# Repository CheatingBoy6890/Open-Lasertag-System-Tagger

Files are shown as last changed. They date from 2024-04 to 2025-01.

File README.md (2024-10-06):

<div align="center">
  
PCBWay
###### Partnering with PCBway.
</div>
<br/>

# Open-Lasertag-System

_DSC8902

---


https://commons.wikimedia.org/w/index.php?curid=1668938

Warning: This project uses lasers. Be sure to **always** do your own testing by meassuring voltage and current and by looking in datasheets. I am **not** responsible for any injuries you encounter from using this project. Also make sure to wear proper eye-protection.

---

## What is Open-Lasertag-System?

Open-Lasertag-System is our approach to a build Lasertag that can be played anywhere without the need of setting up repeaters or servers, whilst beeing pretty easy to build and extend to fit your needs. It works decentral using a WIFI mesh,so the range and fun extends the more players you have!

Currently the project consists of five parts:

1.  The Taggers are fully functional with features such as different firemodes and score synchronization
2.  The vests are functional and connect wirelessly with the corresponding tagger
3.  Targets : For those who don't want to shoot at each other can just shoot at these. The plan also ist to intergrate the further into the system for modes like capture the Flag
4.  Logger: Counts wich target have been hit by whom
5.  There's a Laser grenade planned

---

## What is this repository?

This is the repository for the taggers of the system. here you'll find all the neccessary files on how to build a tagger your self.

**The instructions on building can be found in the** [**Hardware folder**](https://github.com/CheatingBoy6890/Open-Lasertag-System-Tagger/tree/main/Hardware)

**You can also buy prepackaged set on ebay: https://www.ebay.de/itm/226291836696 (only available in Germany)**

**What you'll need:**

- A 3D-printer capable of printing 20cmx20cm
- Soldering iron
- An ESP 8266 wemos d1 mini
- A piece of LED strip 6 LEDs ws2812b
- OLED 1,3" sh1106 or ssd1306
- At least slightly transparent filament
- PCB or perf matrix board
- Cable
- Pin headers
- Crimp equipment and or breadboard cables
- 16 or 32 Ω 40mm speaker
- 2x electrolytic capacitor min 5V 25uF
- 2x ceramic capacitor min 5V about 0,1uF
- 3x BC547 or other npn transistor with simlar pinout
- 2x Red laserpointer head
- Tsop 4838
- LACO LCU985072A Laserdiode, 50 mW, 980 nm, Ø 5,6 mm
- 2x Button
- Switch
- 2x Resistor 10kΩ
- Resistor 1kΩ
- Resistor 160Ω
- Resistor 12Ω
- Resistor 39Ω
- Resistor 0Ω (Replace with higher resistance when your speaker has below 16Ω)
- Resistor 100kΩ (only PCB V3)
- Resistor 200kΩ (only PCB V3)
- FRX04060F resetable fuse (only PCB V3.1)
- Battery clip
- Battery holder 4 AA batteries
- 6x Screw M4 x40mm
- 3mm diameter piece of metal rod or pipe
- Rubber band

- cover lens (optional)
- Time

  ## Who are we?

  We are two German students. Since we are twins, we build and programm a lot of projects together. We create all of our projects in our free time. Feel free to mail any questions to cyberfox3801@proton.me .
  We want to motivate people to discover what is possible using 3D printing and microcontrollers. \
  The most productive worker of our small group is our cat Susi. 

Congratulations you made it to the end of this readme. If you want this to be longer consider buying us a coffe (https://www.paypal.com/donate/?hosted_button_id=2RZBTA5GMNH6S) so we can make all files longer and better
and don't forget to cuddle your cat!

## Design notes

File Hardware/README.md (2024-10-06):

<div align="center">
  
PCBWay
###### Partnering with PCBway.
</div>
<br/>

# Hardware

## General Information

Warning: This project uses lasers. Be sure to **always** do your own testing by meassuring voltage and current and by looking in datasheets. I am **not** responsible for any injuries you encounter from using this project. Also make sure to wear proper eye-protection.

---

**The Tagger runs using 4 1,2V NiMh batteries! Don't use voltages greater than 5V in order to power the Tagger.**

---

Double check that you've soldered the electrolytic capacitors in the right orientation.

---

## 3D Printing

All 3D source files are in the FCstd format. kThey can be opened and edited using <a href ="www.freecad.org/index.php">Freecad</a>.
For printing you can just use the given .stl files.

---

## Perf matrix board

We suggest the perf matrix board version only for people who know what they're doing. If you just want to build your own tagger without changing the layout later we suggest using a PCB.
The schematic for using a breadboard is in the .diy format. These files can be viewed and edited using <a href ="https://bancika.github.io/diy-layout-creator/">DIY Layout creator</a>.

---

## PCB

We created the pcb layout with <a href="https://www.kicad.org/">KiCad</a>. You can easily order really nice high-quality PCBs from our partner [PCBWay](www.pcbway.com) by using the PCBWay plugin in KiCAD following this [turorial](https://www.pcbway.com/blog/News/PCBWay_Plug_In_for_KiCad_3ea6219c.html), exporting the gerber files manually like explained [here](https://www.pcbway.com/blog/help_center/How_to_Generate_Gerber_and_Drill_Files_in_KiCad_7_0_ab0d12bb.html) or use the files in the repository (possibly outdated or not-yet available).

 
<div align=center>
   
###### Pictures from [Lasertag's Grenade](https://github.com/CheatingBoy6890/Open-Lasertag-System-Grenade) PCB
</div>
---

## The Displays

When buying Oleds from not-so-trustworthy sellers on Amazon or Aliexpress, they might claim to send you an SSD_1306 Oled, but in fact it's one with an SH_1106 controller. You notice that problem, when the pixles on the display are shifted a bit, the you can just change the Display settings to SH_1106 in the icons.h file.

---

## The code

To flash the program to your ESP8266 you need to have <a href="https://code.visualstudio.com/">Visual Studio Code</a> and the platformio extension installed. If you haven't you can follow this tutorial:
<a>https://randomnerdtutorials.com/vs-code-platformio-ide-esp32-esp8266-arduino/</a> To flash an ESP8266 from Windows you might need additional drivers, you'll find a tutorial on this here https://randomnerdtutorials.com/install-esp32-esp8266-usb-drivers-cp210x-windows/

## Building the Tagger

1. Make sure you have got all the required parts _DSC8940Widerstände
1. Slice the stl files and print them with a 3d-printer
1. Remove the supports from the 3D printed parts 3D-Parts
1. Flash your ESP8266 with the programm and the sound files
   - Open Visual Studio Code
   - Click Open Folder and choose the Folder you downloaded: Open_Folder
   - When it askes you, click "trust the authors: trust_the_authors
   - Connect the ESP8266 to your pc and click "upload" to upload the program and then press "build filesystem image" and after that "upload file system image: Upload_1
1. Solder the pins to your ESP

   - Make sure that the ESP8266 board is facing the top.Solder_pins (check and cross from pixabay Bild von <a href="https://pixabay.com/de/users/janjf93-3084263/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">Jan</a> auf <a href="https://pixabay.com/de//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">Pixabay</a> Bild von <a href="https://pixabay.com/de/users/openclipart-vectors-30363/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">OpenClipart-Vectors</a> auf <a href="https://pixabay.com/de//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">Pixabay</a>

1. Solder all components and pin headers to the PCB or matrix board finished
1. Solder cables to the buttons,the TSOP and the speaker and crimp sockets at the ends if needed
1. Put the IR-LaserDiode in the casing:
   - Take one of the red laser pointer heads and tear out the laser
   - Grind down about 1mm of the laser pointer head housing
   - Glue the infrared laser in the housing IR-LaserDiode
1. Solder cables to the LED strip and crimp sockets
1. Solder the red cable of your battery clip to the switch and connect the power pin headers on the PCB
1. Glue the lasers ,the Tsop ,the LED strip ,the speaker and the switch in place
1. Connect all your components to the PCB in the gun housing
1. Cut a 3mm diamter x 35mm piece of metal rod or pipe
1. Put in the trigger using the piece of rod
1. Tense the rubber band between the trigger and the fixture
1. Put in the battery pack with 4 AA 1,2V NiMh batteries
1. Close the Tagger and screw the two parts together
1. Slightly pull the trigger and then turn on power
1. Have fun

## Optional

If you have the PCB_v2 but want to meassure the voltage of the batteries you can use this sketchy solution: Meassure_voltage
Don't forget to uncomment the #define CHECK_BATTERY in main.cpp

If you play without vest or you run into receiving issues, add a cover lens on the IR-receiver.



Glue it to one half of the tagger, so you can still open it.



## Tips and Tricks

Making sure the Infrared laser works is possible by checking it with a phone camera. This works with every decent phone, so iPhones obviously do not work.
The 1mw laser can only be seen in darkness.
Be aware that strong infrared lasers can permanently damage your camera sensor.

If your tagger keeps crashing when pressing "shoot" you'll need to go into the onShoot() function and add IRAM_ATTR to every method called here e.g. change
`bool Task::isEnabled() { return iStatus.enabled; }`
in .pio/libdeps/d1_mini/TaskScheduler/src/TaskScheduler.h to:
`bool IRAM_ATTR Task::isEnabled() { return iStatus.enabled; }`
Do this for the Task::restart() method and al other as well.

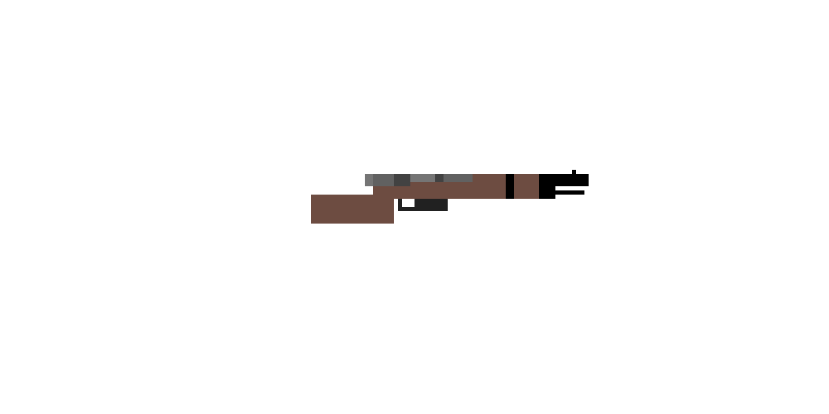
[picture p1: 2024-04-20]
images/sr2766a2aaa83aws3.png

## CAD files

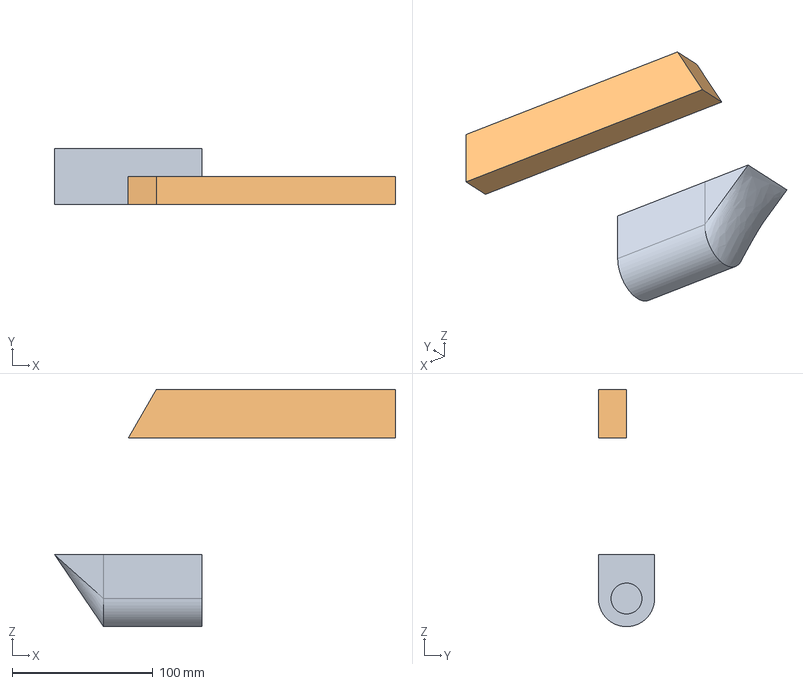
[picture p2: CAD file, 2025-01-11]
Hardware/3D/Tagger3_test.FCStd
242.4 x 40.0 x 168.7 mm
Grip2
Barrel_left

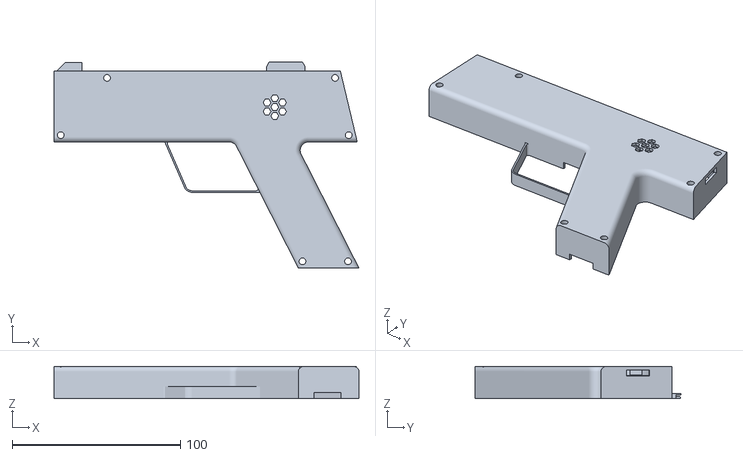
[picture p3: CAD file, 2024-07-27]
Hardware/3D/TaggerPart1-Part.stl
181.0 x 122.4 x 19.0

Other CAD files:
Hardware/3D/TaggerPart2-Part.stl
Hardware/3D/TaggerPart1.FCStd
Hardware/3D/TaggerPart2.FCStd

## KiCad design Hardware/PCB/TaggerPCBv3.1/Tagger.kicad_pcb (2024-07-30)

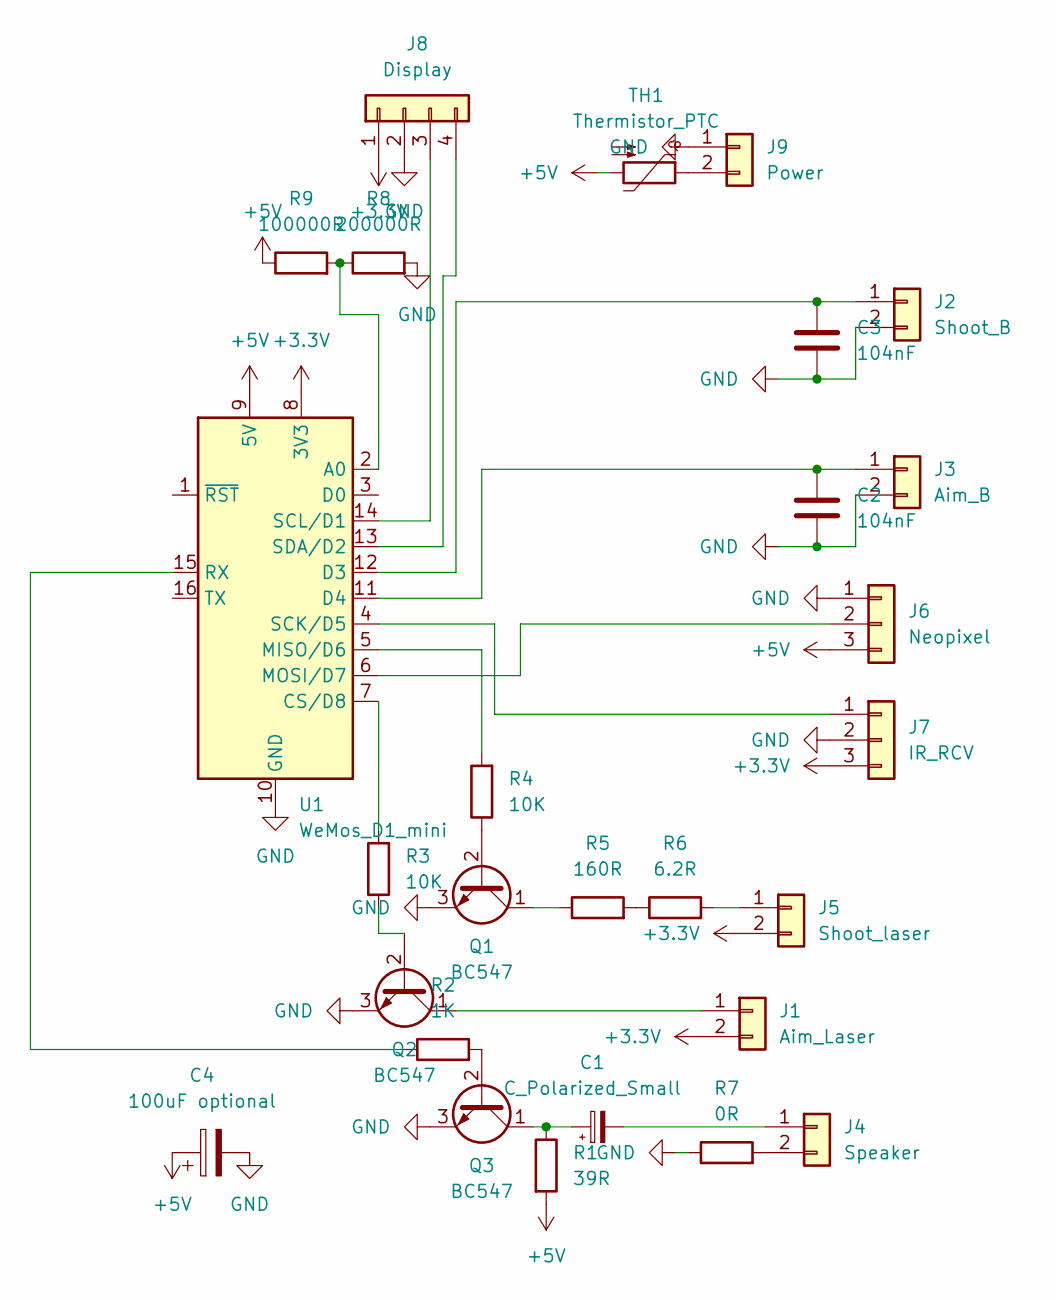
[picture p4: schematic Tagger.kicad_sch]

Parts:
C1: C_Polarized_Small; C_Disc_D5.0mm_W2.5mm_P2.50mm
C2, C3: 104nF; C_Disc_D5.0mm_W2.5mm_P2.50mm
C4: 100uF optional; CP_Radial_D6.3mm_P2.50mm
J1: Aim_Laser; PinHeader_1x02_P2.54mm_Vertical
J2: Shoot_B; PinHeader_1x02_P2.54mm_Vertical
J3: Aim_B; PinHeader_1x02_P2.54mm_Vertical
J4: Speaker; PinHeader_1x02_P2.54mm_Vertical
J5: Shoot_laser; PinHeader_1x02_P2.54mm_Vertical
J6: Neopixel; PinHeader_1x03_P2.54mm_Vertical
J7: IR_RCV; PinHeader_1x03_P2.54mm_Vertical
J8: Display; PinHeader_1x04_P2.54mm_Vertical
J9: Power; PinHeader_1x02_P2.54mm_Vertical
Q1, Q2, Q3: BC547; TO-92_Inline
R1: 39R; R_Axial_DIN0204_L3.6mm_D1.6mm_P7.62mm_Horizontal
R2: 1K; R_Axial_DIN0204_L3.6mm_D1.6mm_P7.62mm_Horizontal
R3, R4: 10K; R_Axial_DIN0204_L3.6mm_D1.6mm_P7.62mm_Horizontal
R5: 160R; R_Axial_DIN0204_L3.6mm_D1.6mm_P7.62mm_Horizontal
R6: 6.2R; R_Axial_DIN0204_L3.6mm_D1.6mm_P7.62mm_Horizontal
R7: 0R; R_Axial_DIN0204_L3.6mm_D1.6mm_P7.62mm_Horizontal
R8: 200000R; R_Axial_DIN0204_L3.6mm_D1.6mm_P7.62mm_Horizontal
R9: 100000R; R_Axial_DIN0204_L3.6mm_D1.6mm_P7.62mm_Horizontal
TH1: Thermistor_PTC; C_Disc_D5.0mm_W2.5mm_P2.50mm
U1: WeMos_D1_mini; WEMOS_D1_mini_light

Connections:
+3.3V: J1.2, J5.2, J7.3, J8.1, U1.8 (3V3)
+5V: C4.1, J6.3, R1.2, R9.1, TH1.2, U1.9 (5V)
GND: C2.1, C3.1, C4.2, J2.2, J3.2, J6.1, J7.2, J8.2, J9.1, Q1.3 (E), Q2.3 (E), Q3.3 (E), R7.1, R8.2, U1.10 (GND)
unnamed: J1.1, Q2.1 (C)
unnamed: C3.2, J2.1, U1.12 (D3)
unnamed: C2.2, J3.1, U1.11 (D4)
unnamed: C1.2, J4.1
unnamed: J4.2, R7.2
unnamed: J5.1, R6.2
unnamed: J6.2, U1.6 (MOSI/D7)
unnamed: J7.1, U1.4 (SCK/D5)
unnamed: J8.3, U1.14 (SCL/D1)
unnamed: J8.4, U1.13 (SDA/D2)
unnamed: J9.2, TH1.1
unnamed: Q1.2 (B), R4.1
unnamed: Q1.1 (C), R5.1
unnamed: Q2.2 (B), R3.1
unnamed: Q3.2 (B), R2.2
unnamed: C1.1, Q3.1 (C), R1.1
unnamed: R5.2, R6.1
unnamed: R8.1, R9.2, U1.2 (A0)
unnamed: R3.2, U1.7 (CS/D8)
unnamed: R4.2, U1.5 (MISO/D6)
unnamed: R2.1, U1.15 (RX)

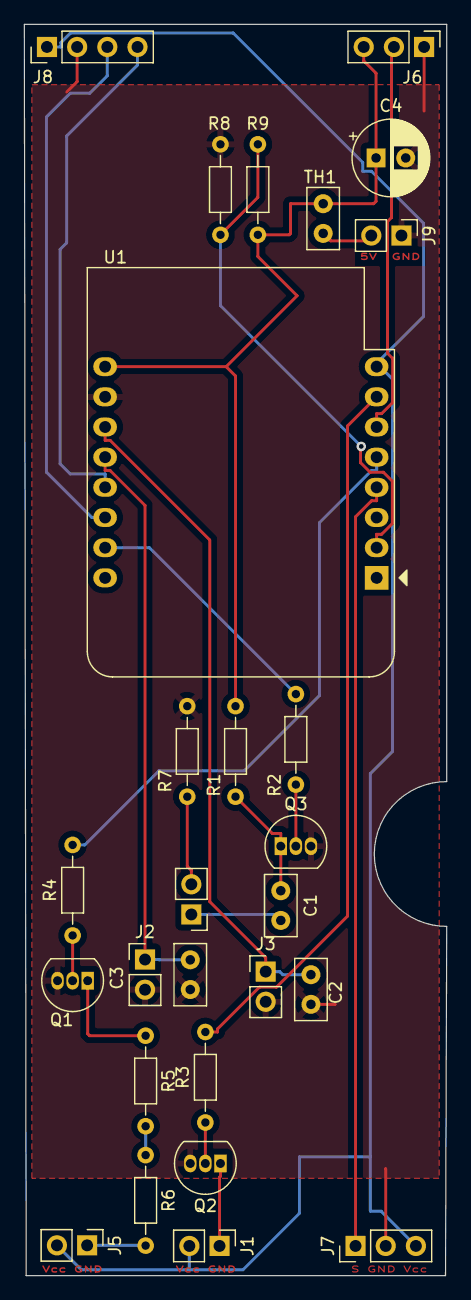
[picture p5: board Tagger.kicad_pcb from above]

Board: 2 copper layers, 35.6 x 105.3 mm, 27 parts (0 on the bottom side), 24 nets.

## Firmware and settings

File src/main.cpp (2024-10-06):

/*
Copyright (c) 2024, Silas Hille
All rights reserved.

This source code is licensed under the BSD-style license found in the
LICENSE file in the root directory of this source tree.

*/
#include <Arduino.h>

#include <U8g2lib.h>

// #include "AudioFileSourceSPIFFS.h"
#include "AudioFileSourceLittleFS.h"
// #include "AudioGeneratorMP3.h"
// #include "AudioGeneratorFLAC.h"
#include <AudioGeneratorWAV.h>
#include "AudioOutputI2SNoDAC.h"

#include <IRremoteESP8266.h>
#include <IRrecv.h>
#include <IRutils.h>
#include <IRsend.h>

// #include <2g13ucheduler.h>
#include <ArduinoJson.h>
#include <painlessMesh.h>

#include <Adafruit_NeoPixel.h>

#include "weapon.h"
#include "neopixel_config.h"
#include "team_config.h"

const uint8_t SPEAKER_PIN = RX;

const uint8_t PIXEL_PIN = D7;

const uint8_t SHOOT_BUTTON = D3;
const uint8_t AIM_BUTTON = D4;

const uint8_t AIM_LASER = D8;
const uint8_t IR_LASER = D6;

const uint8_t IR_RECEIVER = D5;

const char *SCORE_MESSAGE PROGMEM = "Never gonna give you up!";
const char *VEST_CONNECT_ACKNOWLEDGE_MESSAGE PROGMEM = "bound";

const char *DEATH_SOUND PROGMEM = "/death.wav";
const char *RELOAD_SOUND PROGMEM = "/reload.wav";
const char *EMPTY_SOUND PROGMEM = "/empty.wav";
const char *SHOOT_SOUND PROGMEM = "/shoot.wav";

#define DEBUG_MODE             // Enable Debug Serial-prints
#define TEAM_SelTime 5000      // Time when turning on to select teams
#define VEST_CONNECTTIME 15000 // time to connect a vest

#define Down_Time 5000 // Time it takes to regen when you've been shot
// #define SHOOT_DELAY 150         // Firerate
// #define TIME_BEFORE_RELOAD 1000 // Time you have to hold the shoot button down before starting to reload
// #define RELOAD_INTERVAL 450
#define SEND_POINT_INTERVAL 5000 // The between sending people who killed you to score a point. Don't set too low, since it's pretty time intensive.

#define IR_CHECK_INTERVAL 100

#define CHECK_BATTERY // Check the voltage of the battery, comment this out if you've got PCB_v2 since it doesn't have the resistors to meassure the voltage.

// #define PISTOL_DAMMAGE 9 // The index of the Dammage array in team_config.h
// #define MAX_BULLETS 14   // With BULLET_WIDTH 10 and space 30 x 90 and Bullet_WIDTH 10 theres Space for 48 bullets
#define BULLET_WIDTH 10
#define SPACE_FOR_BULLETS_Y 90 // the y-space  from the bottom (128)of the Display. to  * bullets to.
#define SPACE_FOR_BULLETS_X 30 // The space for bullets in x direction counted from the left (0) of the Display.
// const uint8_t BULLET_HEIGHT = max(1,((min(SPACE_FOR_BULLETS / MAX_BULLETS, 7) + 1) >> 1 << 1) -1);  // set the bullet size so they fit on screen, max 7 pixels, because bigger looks stupid. Some magic to make it odd so the circle will fit. Minimum is 1 so there's no overflow.
const uint8_t BULLET_HEIGHT = 5; // must be odd
IRrecv receiver(IR_RECEIVER);
decode_results results;

IRsend transmitter(IR_LASER);

AudioFileSourceLittleFS *file;
// AudioGeneratorMP3a *decoder;
AudioGeneratorWAV *decoder;
AudioOutputI2SNoDAC *out;

Scheduler userScheduler;
painlessMesh Lasermesh;

uint8_t myWeaponIndex = 0;

Adafruit_NeoPixel pixels(LED_NUM, PIXEL_PIN, NEO_GRB + NEO_KHZ800);

void drawammunition(uint8_t x, uint8_t y);
void drawbullets(uint8_t first = 0, uint8_t last = weapons[myWeaponIndex].getMaxBullets());

void ammonition_led();
void updatePixels();

void TaskAmmoCallback();
void TaskRegenerateCallback();
void TaskShootCallback();

void playAudio(const char *path);
void loopAudio();
void mesassure_battery();

void printTeamInformation();
void teamselect();
void weaponSelect();
void draw_connected_icon();
void drawHP(void);
void drawScore(void);

void IRRecv();

void onShoot();
void handleShootInterrupt();
void sendMilesTag(uint8_t player, uint8_t team, uint8_t dammage);
void CheckIRresults(decode_type_t decode_type, uint8_t teamId, uint16_t playerIndex, uint8_t damage);
void IRAM_ATTR onLaserButtonChange();

void MeshReceivedCallback(uint32_t from, String &msg);
void MeshNewConnectionCallback(uint32_t nodeId);
void MeshChangedConnectionCallback();
void nodeTimeAdjustedCallback(int32_t offset);

void send_who_killed_me();
void updateScores();

// Task DisplayStuff(TASK_SECOND * 5, TASK_FOREVER, &display);
Task TaskLoopAudio(TASK_MILLISECOND * 10, TASK_FOREVER, &loopAudio);
Task TaskReload(0, weapons[myWeaponIndex].getMaxBullets(), &TaskAmmoCallback);
Task TaskRegenerate(Down_Time, 1, &TaskRegenerateCallback); // Specifying with Down_Time isn't really needed because it schouldn't have an impact. But better to be safe, right?
Task TaskSendScorePoints(SEND_POINT_INTERVAL, TASK_FOREVER, &send_who_killed_me);
Task TaskSyncPoints(10000, TASK_FOREVER, &updateScores);
Task TaskCheckIR(IR_CHECK_INTERVAL, TASK_FOREVER, &IRRecv);
Task TaskShoot(100, TASK_FOREVER, &TaskShootCallback);
Task TaskHandleShootInterrupt(10, TASK_FOREVER, &handleShootInterrupt);

uint8_t bullets = weapons[myWeaponIndex].getMaxBullets();

uint64_t debounce_shoot;

uint32_t boundvest = 0; // set to 0 to enable vest selection before game start.

uint8_t hp = 100;
bool alive = true;
bool isRunning = false;
bool enableAimLaser = true; // Todo: Maybe it's possible to debuff the other team so they cant use their lasers. Just a thought.
volatile bool shootButtonpressed = false;
/*
  ____       _
 / ___|  ___| |_ _   _ _ __
 \___ \ / _ \ __| | | | '_ \
  ___) |  __/ |_| |_| | |_) |
 |____/ \___|\__|\__,_| .__/
                      |_|
*/
void setup()
{
  Serial.begin(115200);
  Serial.println(F("setup"));
  pinMode(SDA, OUTPUT);
  pinMode(SCL, OUTPUT);
  // pinMode(IR_LASER, OUTPUT);
  pinMode(AIM_LASER, OUTPUT);
  pinMode(SHOOT_BUTTON, INPUT_PULLUP); // ESP8266 is buggy, so sometimes the Pin is only pulled up when the pinMode ist INPUT without pullup specified.
  pinMode(AIM_BUTTON, INPUT_PULLUP);   // ESP8266 is buggy, so sometimes the Pin is only pulled up when the pinMode ist INPUT without pullup specified.
  // pinMode(IR_RECEIVER,INPUT);
  pinMode(PIXEL_PIN, OUTPUT);

  //  digitalWrite(IR_LASER,LOW);
  //  delay(10000);

  // digitalWrite(IR_LASER,HIGH);
  // delay(10000);

  Display.begin();
  Display.setFont(u8g2_font_tinytim_tf);
  Display.setDrawColor(1);
  Display.setBitmapMode(1);
  // SPIFFS.begin();
  LittleFS.begin();
  pixels.begin();

  weaponSelect();
  // weapons[myWeaponIndex].DrawIcon(Display,20,20);
  weapons[myWeaponIndex].createShootTask(TaskShoot);
  weapons[myWeaponIndex].drawIcon(0, 0);
  TaskReload.setInterval(weapons[myWeaponIndex].getReloadInterval());
  Display.sendBuffer();
  delay(1000);
  // pixels.SetPixelColor(0,RgbColor(20,100,255));
  // pixels.Show();

  audioLogger = &Serial;

  file = new AudioFileSourceLittleFS(DEATH_SOUND);
  decoder = new AudioGeneratorWAV();
  decoder->SetBufferSize(500);
  out = new AudioOutputI2SNoDAC();
  out->SetOutputModeMono(true);
  out->SetGain(1);
  // mp3->begin(file, out);
  // userScheduler.init();

  // digitalWrite(D8,LOW);
  // delay(5000);

  Lasermesh.setDebugMsgTypes(ERROR | DEBUG | STARTUP); // set before init() so that you can see error messages

  Lasermesh.init(F("Lasermesh"), F("Password"), &userScheduler, 5555);
  Lasermesh.onReceive(&MeshReceivedCallback);
  Lasermesh.onNewConnection(&MeshNewConnectionCallback);
  Lasermesh.onChangedConnections(&MeshChangedConnectionCallback);
  Lasermesh.onNodeTimeAdjusted(&nodeTimeAdjustedCallback);

#ifdef DEBUG_MODE
  Serial.print(F("NodeId = "));
  Serial.println(Lasermesh.getNodeId());
#endif
  userScheduler.addTask(TaskReload);
  userScheduler.addTask(TaskRegenerate);
  userScheduler.addTask(TaskSendScorePoints);
  userScheduler.addTask(TaskCheckIR);
  userScheduler.addTask(TaskLoopAudio);
  userScheduler.addTask(TaskShoot);
  userScheduler.addTask(TaskSyncPoints);
  userScheduler.addTask(TaskHandleShootInterrupt);
  TaskSendScorePoints.enable();

  teamselect();

  // Remind players how to connect a vest
  Display.clearBuffer();
  Display.setCursor(0, 40);
  Display.print(F("Just shoot at\na vest to\nconnect to it"));
  Display.sendBuffer();
  delay(1000);

  pinMode(AIM_BUTTON, INPUT_PULLUP); // Set pinmode again because ESP8266audio blocks these for I2s which isn't needed. With redeclaration there's no problem.
  pinMode(AIM_LASER, OUTPUT);
  // pinMode(IR_LASER,OUTPUT);

  // for(int i = 0; i < 20; i++)
  // {
  //   digitalWrite(IR_LASER,HIGH);
  //   delay(1000);
  //   digitalWrite(IR_LASER,LOW);
  //   delay(1000);
  // }
  // transmitter.enableIROut(36, 50);
  receiver.enableIRIn(); // sets the Pin to INPUT automatically
  transmitter.begin();

  attachInterrupt(digitalPinToInterrupt(AIM_BUTTON), onLaserButtonChange, CHANGE);

  attachInterrupt(digitalPinToInterrupt(SHOOT_BUTTON), onShoot, FALLING);
  TaskHandleShootInterrupt.enable();

  drawbullets(0, bullets);
  // drawHP();
  // drawScore();
  // Display.sendBuffer();

  alive = true;
  TaskRegenerate.enable();

  updatePixels();
  TaskLoopAudio.enable();
  
  playAudio(DEATH_SOUND);
}

/*
  _
 | |    ___   ___  _ __
 | |   / _ \ / _ \| '_ \
 | |__| (_) | (_) | |_) |
 |_____\___/ \___/| .__/
                  |_|
*/

void loop()
{
  // digitalWrite(AIM_LASER,digitalRead(AIM_BUTTON));
  // loopAudio();
  // Serial.printf("D4 is %i\n", digitalRead(D4));

  // userScheduler.execute();

  Lasermesh.update();

  // delay(1000);
  // if (millis() >= nextTime)
  // {
  //   // int j = 119 - bullet_number * 9;
  //   // bullet_number++;
  //   // if (bullet_number > 8)
  //   // {
  //   //   bullet_number = 1;
  //   //   Display.clearBuffer();
  //   // }
  //   // drawammunition(j);
  //   // Display.sendBuffer();
  //   nextTime = millis() + 800;
  //   playAudio("/reload.mp3");
  // }
}

// put function definitions here:
void drawammunition(uint8_t x, uint8_t y)
{
  Display.drawBox(x, y, BULLET_WIDTH, BULLET_HEIGHT);
  // Display.drawFilledEllipse(BULLET_WIDTH /* +x */, y + ((int)BULLET_HEIGHT / 2), 4, ((int)BULLET_HEIGHT / 2), U8G2_DRAW_ALL); // y + Floored half of the height of the box
  Display.drawDisc(BULLET_WIDTH + x, y + BULLET_HEIGHT / 2, BULLET_HEIGHT / 2, U8G2_DRAW_LOWER_RIGHT | U8G2_DRAW_UPPER_RIGHT);
}

// Actually draws everything like team info and hp
void drawbullets(uint8_t first, uint8_t last)
{
  Display.clearBuffer();

  printTeamInformation();
  drawScore();

  if (boundvest != 0 && Lasermesh.isConnected(boundvest))
  {
    draw_connected_icon();
  }
  // uint16_t bullets_left = last;
  // for (int i = first; i < last; i++, bullets_left--)
  // {
  //   uint8_t y = SPACE_FOR_BULLETS - i * (BULLET_HEIGHT  +1);
  //   drawammunition(0,y); // leave blank space between bullets.
  //   if(y <= Display.getHeight() - SPACE_FOR_BULLETS){
  //     break;
  //   }
  // }
  uint8_t x = 0;
  uint8_t y = Display.getHeight() - BULLET_HEIGHT;

  for (uint8_t i = first; i < last; i++)
  {
    drawammunition(x, y);
    if (y >= (Display.getHeight() - SPACE_FOR_BULLETS_Y))
    {
      y = y - (BULLET_HEIGHT + 1);
    }
    else
    {
      x = x + (BULLET_WIDTH + 4);              // leave some space between the collumns
      y = Display.getHeight() - BULLET_HEIGHT; // Reset y to bottom of the screen - Height of bullets.
    }

    if (x > SPACE_FOR_BULLETS_X)
    {
      break;
    }
    // y = (y >= (128 - SPACE_FOR_BULLETS)) ? y - (BULLET_HEIGHT + 1) : (x += BULLET_WIDTH + 4, 128 - BULLET_HEIGHT);
  }

  drawHP();

#ifdef CHECK_BATTERY
  mesassure_battery();
#endif
  Display.sendBuffer();
}
// void fillAmmo(uint8_t amount)
// {
//   // for (uint8_t i = 119; i > 119 - amount * 9; i -= 9)
//   // {
//     drawammunition(i);
//     Serial.printf("reloading cartrige: %i\n", i / 9);
//     // playAudio("/reload.mp3");
//     Display.sendBuffer();
//     delay(700);
//   // }
// }

void TaskAmmoCallback()
{
#ifdef DEBUG_MODE
  Serial.println(F("TaskAmmo"));
#endif
  if (TaskReload.isFirstIteration() && digitalRead(SHOOT_BUTTON)) // If the Button is released when reloading starts disable the task
  {
    // TaskReload.restartDelayed(10000); // reset the runcounter to 0 the delay is completely unimportant.
    TaskReload.enable(); // Reset runcounter when Task ends.
    TaskReload.disable();
    return;
  }
  TaskShoot.setIterations(weapons[myWeaponIndex].getIterations());
  if (bullets >= weapons[myWeaponIndex].getMaxBullets()) // If Ammo is already full or higher due to a bug disable.
  {
    TaskReload.enable(); // Reset runcounter when Task ends.
    TaskReload.disable();
  }
  else
  {
    bullets++;
    drawbullets(0, bullets);
    Display.sendBuffer();
    updatePixels();
    // strip.SetPixelColor(0,RgbColor(255,255,255));
    // strip.Show();
    // if(t1.getRunCounter()==2){digitalWrite(BUILTIN_LED,LOW);}
    playAudio(RELOAD_SOUND);
  }

  // if(TaskReload.isLastIteration())
  // {TaskReload.restartDelayed(1000);
  //   TaskReload.disable();
  // }
  if (TaskReload.isLastIteration())
  {
    TaskReload.enable(); // Reset runcounter when Task ends.
  }
}

void TaskRegenerateCallback()
{
#ifdef DEBUG_MODE
  Serial.println(F("TaskRegenerate"));
#endif
  hp = 100;
  alive = true;
  bullets = weapons[myWeaponIndex].getMaxBullets();
  drawbullets(0, bullets);
  Display.sendBuffer();
  if (boundvest != 0)
  {
    Lasermesh.sendSingle(boundvest, "alive");
  }
}

void playAudio(const char *path)
{
  if (decoder->isRunning())
  {
    decoder->stop();
    // delete mp3;
    // out->flush();
    // file->close();

    // out->stop();

    // delete file;

    // delete out;

    // file = new AudioFileSourceSPIFFS(path.c_str());
    // mp3 = new AudioGeneratorMP3();
    // out = new AudioOutputI2SNoDAC();
    // out->SetOutputModeMono(true);
    // out->SetGain(1);
  }
  file->open(path);
  // out->begin();
  decoder->begin(file, out);
}

void loopAudio()
{
#ifdef DEBUG_MODE
  if (TaskLoopAudio.getRunCounter() % 100 == 1)
  {
    Serial.print(F("Free heap: "));
    Serial.println(ESP.getFreeHeap());
  }
#endif

  if (decoder->isRunning())
  {
    if (!decoder->loop())
    {
      decoder->stop();
      // file->close();
    }
  }
}

void printTeamInformation()
{
  // Display.clearBuffer();
  // Display.drawStr(0, 5, "Rot: 12");
  // Display.drawStr(0, 11, "Gr�n: 19");
  // Display.drawStr(0, 17, "Blau: 17");
  // Display.drawStr(0, 23, "Gelb: 9");
  Display.setCursor(0, 7);
  for (auto i : TeamList)
  { // iterate trough all teams
    Display.print((i.name + ": " + i.score).c_str());
    Display.setCursor(0, Display.getCursorY() + 7);
  }
  // for(int i = 128;i>23;i--){
  //   Display.drawBox(50,i,10,128);
  //   delay(10);
  //   Display.sendBuffer();
  // }
  // drawammunition(120);
  // fillAmmo(10);
}

void draw_connected_icon()
{

  Display.drawXBMP(Display.getWidth() - 15, 0, Cast_icon_width, Cast_icon_height, Cast_icon_bits);
}

// Needed for painless library
void MeshReceivedCallback(uint32_t from, String &msg)
{
  // Serial.printf("startHere: Received from %u msg=%s\n", from, msg.c_str());
  // Serial.println(msg);
  Serial.print(F("--> New message from: "));
  Serial.println(from);
  Serial.print(F("Message: "));
  Serial.println(msg);

  if (msg == SCORE_MESSAGE)
  {
#ifdef DEBUG_MODE
    Serial.println(F("Got a point"));
#endif
    myPoints++;
    TeamList[myTeamId].score++; // Todo: sync points between players.
    drawbullets(0, bullets);
  }
  else if (msg.startsWith("IR-Data:"))
  {
    uint32_t value = strtoul(msg.substring(msg.indexOf(":") + 1).c_str(), nullptr, 10);
#ifdef DEBUG_MODE
    Serial.println(value);
#endif
    CheckIRresults(MILESTAG2, (value & 0B110000) >> 4, value >> 6, value & 0b001111);
  }
  else if (msg == VEST_CONNECT_ACKNOWLEDGE_MESSAGE)
  {
#ifdef DEBUG_MODE
    Serial.println(F("Connected Vest!"));
#endif
    boundvest = from;
    Lasermesh.sendSingle(boundvest, F("alive"));
  }
  else if (msg.startsWith("Sync\n"))
  {
    JsonDocument doc;
    Serial.print(F("Deserialing Json:\n"));
    Serial.println(msg.substring(msg.indexOf('{')));
    deserializeJson(doc, msg.substring(msg.indexOf('{')));
    doc[TeamList[myTeamId].name] = doc[TeamList[myTeamId].name] + myPoints;
    // If your the last player you don't relay the message but broadcast it.
    if (players.back() == Lasermesh.getNodeId())
    {
      String json;
      serializeJson(doc, json);
      String msg = "Points\n" + json;
      Lasermesh.sendBroadcast(msg, true);
    }
    else
    {
      String json;
      serializeJson(doc, json);
      String msg = "Sync\n" + json;
      Lasermesh.sendSingle(players[myPlayerId + 1], msg);
    }
  }

  if (msg.startsWith("Points\n"))
  {
    JsonDocument doc;
    deserializeJson(doc, msg.substring(msg.indexOf('{')));
    // You have to use references in order to change values
    for (team &t : TeamList)
    {
      t.score = doc[t.name];
    }
    drawbullets(0, bullets);
  }
}

void MeshNewConnectionCallback(uint32_t nodeId)
{
  // Serial.printf("--> startHere: New Connection, nodeId = %u\n", nodeId);
  Serial.print(F("--> New Connection from: "));
  Serial.println(nodeId);
}

void MeshChangedConnectionCallback()
{
  Serial.println(F("Changed connections"));
  if (isRunning == false)
  {
    players.clear();
    for (const uint32_t &node : Lasermesh.getNodeList(true))
    {
      players.push_back(node);
    }
    players.shrink_to_fit();
    std::sort(players.begin(), players.end());
    Serial.printf("Player id is: %u \n", std::distance(players.begin(), std::find(players.begin(), players.end(), Lasermesh.getNodeId())));
    myPlayerId = std::distance(players.begin(), std::find(players.begin(), players.end(), Lasermesh.getNodeId()));
  }
}

void nodeTimeAdjustedCallback(int32_t offset)
{
  Serial.printf("Adjusted time %u. Offset = %d\n", Lasermesh.getNodeTime(), offset);
}

void IRAM_ATTR onLaserButtonChange()
{
  if (enableAimLaser)
  {
    digitalWrite(AIM_LASER, digitalRead(AIM_BUTTON)); // Turn on the Aimlaser when the Button is released. HIGH when button is open because of pullup.
  }
}

void IRAM_ATTR onShoot() // Send a Milestag2 Package, Play sounds and start the ReloadTask for later. Reload task is disabled when the Button is releasded before TIME_BEFORE_RELOAD
{

  shootButtonpressed = true;
  // Serial.println("Interrupt!");
  // noInterrupts();

  // interrupts();
}

void handleShootInterrupt()
{
  if (shootButtonpressed && alive && !TaskShoot.isEnabled())
  {
    // if (!digitalRead(SHOOT_BUTTON))
    // {
    TaskShoot.restart /*Delayed*/ (/*weapons[myWeaponIndex].getTimeBeforeShot()*/);
    shootButtonpressed = false;
    // }
    // else
    // {
    //   if (TaskReload.getRunCounter() <= 0) // If the task is enabled, but hasn't run yet --> means: Button has been released to early, disable Reload task.
    //   {
    //     TaskReload.disable();

    //     // Serial.println("Disabled Reloading because of Button release!");
    //   }
    //   // Serial.println("Shoot button released");
    //   if (TaskShoot.getIterations() <= 0)
    //   {
    //     TaskShoot.disable();
    //   }
    // }
  }
}

void sendMilesTag(uint8_t playerIndex, uint8_t team, uint8_t dammage)
{
  uint32_t data = 0;
  data = playerIndex;
  data = data << 2;
  data = data + team;
  data = data << 4;
  data = data + dammage;
  // transmitter.sendMilestag2(data);
  transmitter.sendMilestag2(data, 14, 0);
}

void IRRecv()
{

  // Serial.println("Trying to decode");

  if (receiver.decode(&results))
  {

#ifdef DEBUG_MODE // Print on serial only when DEBUG_MODE is defined at the top.
    Serial.println(F("#################"));
    Serial.print(F("Decode Type:"));
    Serial.println(results.decode_type);

    Serial.print(F("Team:"));
    Serial.println(results.command >> 4);

    Serial.print(F("Player:"));
    Serial.println(results.address);

    Serial.print(F("Dammage:"));
    Serial.println(results.command & 0xF);
#endif

    CheckIRresults(results.decode_type, results.command >> 4, results.address, results.command & 0xF);
    receiver.resume(); // Receive the next value
  }
}

inline void CheckIRresults(decode_type_t decode_type, uint8_t teamId, uint16_t playerIndex, uint8_t damage)
{

  // Serial.println("\nDecode Type:" + String(decode_type));

  //     Serial.print("Team:");
  //   Serial.println(teamId);

  //   Serial.print("Player:");
  //   Serial.println(playerIndex);

  if (decode_type == MILESTAG2 && teamId != myTeamId && alive)
  {
    Serial.print(F("Hp: "));
    hp = max(hp - Damage[damage], 0);
    Serial.println(hp);

    if (hp <= 0)
    {
      playAudio(DEATH_SOUND);
      alive = false;
      if (boundvest != 0)
      {
        Lasermesh.sendSingle(boundvest, F("dead"));
      }
      TaskRegenerate.restartDelayed(Down_Time);
      you_killed_me.push_back(players[playerIndex]);
      if (!TaskSendScorePoints.enable()) // Check if the task wasn't  aleready running
      {
        TaskSendScorePoints.forceNextIteration();
      }
    }
    drawbullets(0, bullets);
  }
}

void ammonition_led()
{
  // pixels.SetPixelColor(LED_AMMUNITION, pixels.ColorHSV(bullet_led_color, 255, brightness_per_bullet * bullets));
  uint8_t brightness = (pow(2, (float)bullets / (float)weapons[myWeaponIndex].getMaxBullets()) - 1) * 255;
  pixels.setPixelColor(LED_AMMUNITION, pixels.ColorHSV(bullet_led_color, 255, brightness));
}
void updatePixels()
{
  ammonition_led();

  pixels.setPixelColor(LED_VEST_CONNECTED, boundvest != 0 ? 0xFFFFFF : 0);

  pixels.show();
}

void send_who_killed_me()
{

  Serial.println(F("Now sending who killed me"));
  you_killed_me.shrink_to_fit();
  auto it = you_killed_me.begin();
  while (it != you_killed_me.end())
  {
    uint32_t killer = *it;
    if (Lasermesh.isConnected(killer) && Lasermesh.sendSingle(killer, SCORE_MESSAGE))
    {

      it = you_killed_me.erase(it); // Increments the iterator to next element automatically.
    }
    else
    {
      it++; // If there's an error go to the next element
    }
  }
  if (you_killed_me.empty())
  {
    TaskSendScorePoints.disable();
  }
}
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

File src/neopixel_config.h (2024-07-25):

/*
Copyright (c) 2024, Silas Hille and Linus Hille
All rights reserved.

This source code is licensed under the BSD-style license found in the
LICENSE file in the root directory of this source tree.

*/

// definition for all LEDs on the neopixel strip

#define LED_NUM 6 // Number of LEDs

#define LED_TEAM 0       // LED that shows the team_color from below
#define LED_ALIVE 1      // LED that shows if you're alive
#define LED_AMMUNITION 2 // LEDs brightness shows the amount of ammonition
#define LED_SHOOTING 3   // LED blinks when pressing the shoot-button as an indicator
#define LED_VEST_CONNECTED 5

const uint32_t alive_color = 0x7F7F7F;   // not full brightness white
const uint32_t bullet_led_color = 45511; // HSV color from 0= red to 65536 = red

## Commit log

2024-04-15 Modified some things somewhat working now.
    After a random bit of time the scheduler stops scheduling even when soft-disabling the painlessmesh( another scheduler for the mesh) but the problem persits.
    This commit is to save some work when trying to completely disable the mesh.
    [main.cpp, neopixel_config.h]
2024-04-17 First fully working version (Teamsync missing)
    No crashes so far works like a charm.
    [main.cpp]
2024-04-20 Added 3D print file
    One half of the tagger has been added.
    Also some icons for different weapons.
    [Tagger_fixed_Rounded_Somethings_3.FCStd]
2024-07-22 Added files for 3D printing and PCB/perf board. Removed Tagger_fixed_Rounded_Somethings_3 .
    [Tagger.kicad_pcb, Tagger.kicad_sch, TaggerPart1.FCStd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]
2024-07-25 Update README.md
    Added Laser injuries warning
2024-07-25 Added PCB V3 and moved the perf board schematic out of the PCB folder.
    [Tagger.kicad_pcb, Tagger.kicad_sch]
2024-07-25 Moved Target and Logger to their own Repository
    Fixed the copyright for each source file.
    [Tagger.kicad_pcb, Tagger.kicad_sch, TaggerPart1.FCStd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]
2024-07-27 Changed default Display back to SH_1106 because cheap aliexpress Display which claim to use SSD_1306 Controllers actually use these.
    Added STL file versions of the fcstd files.
    [TaggerPart1-Part.stl, TaggerPart2-Part.stl]
2024-07-30 Added the PCBv3.1
    [Tagger.kicad_pcb, Tagger.kicad_sch]
2024-07-30 Added instructions for sketchy voltage divider
2024-08-12 Made machine gun shoot slower Fixed teamselection to not use timer, but instead wait until trigger is released.
    [main.cpp]
2024-08-13 Fixes random crashes due to some interrupt functions not beeing in IRAM Added an explaination in the Hardware readme so people can fix it them selves unignored the TaskScheduler folder so hopefully p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
    [main.cpp]
2024-08-15 Tried fixing the crash taht happens when something connects to the mesh, wasn't able to.
    [main.cpp]
2024-08-15 Fixes all crashes so far, first fully working version
    [main.cpp]
2024-09-03 Added PCBwayImage
2024-09-03 Added PCBWay advert
2025-01-11 Made a plan for a easier Audio Amplifier circuit.
    [Tagger.kicad_pcb, Tagger3_test.FCStd]
